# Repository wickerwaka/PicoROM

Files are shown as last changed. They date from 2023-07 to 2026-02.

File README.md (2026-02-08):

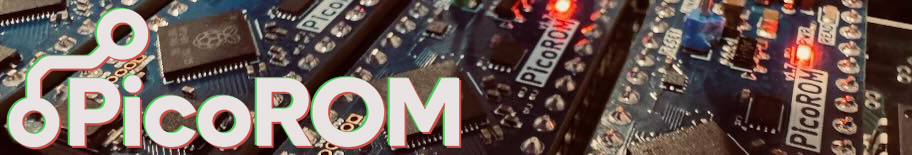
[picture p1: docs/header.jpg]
PicoROM

---
PicoROM is an 8-bit ROM emulator in DIP-32 and DIP-28 form factors. Its primary use case is rapid iteration when experimenting with arcade hardware. PicoROM can emulate ROMs up to 2MBit (256KB) with access times of 70ns. Its compact size allows it to fit into almost any ROM socket regardless of how crowded the board might be.

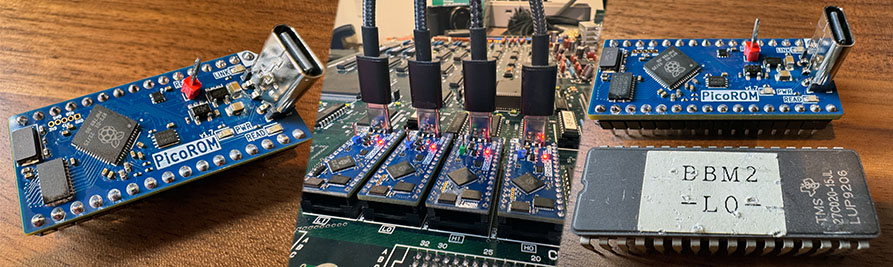
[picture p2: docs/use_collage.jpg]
Header Image


**Features**
- DIP-32 and DIP-28 form factors
- Up to 2MBit (256KB) storage
- 70ns access time
- USB control with integrated firmware updates
- Controllable reset pin

Fully assembled versions are available from [Tindie](https://www.tindie.com/products/pbretro/picorom/).

## Hardware Variants
There are three hardware versions of PicoROM:

- **PicoROM Original (POG)** — Original 32-pin design with a single tri-state reset pin (high, low, or high-impedance). Can be powered by USB or from the host board.
- **PicoROM 28 (P28)** — 28-pin design with dual reset pins (one for high, one for low). Uses split power: the microcontroller is powered by USB or the host board, but external buffers are powered from the 5V input. This reduces power consumption when connected to an unpowered device via USB.
- **PicoROM 32 (P32)** — 32-pin design with all the improvements from P28.

The abbreviated names POG, P28, and P32 identify which firmware image to use for each device.

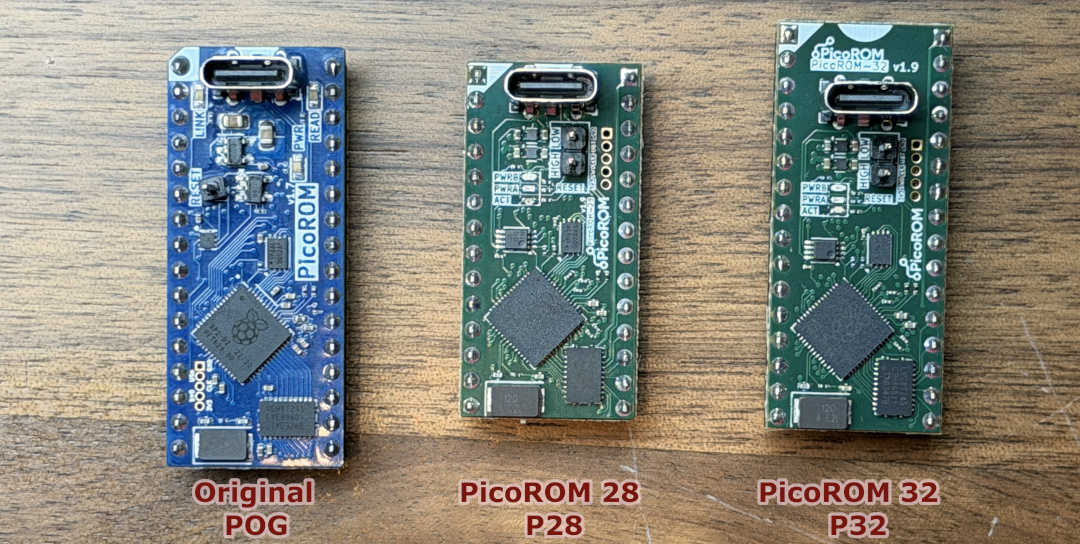
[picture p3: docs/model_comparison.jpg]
Model Comparison


## Version 2.0
Version 2.0 introduced a custom USB protocol, replacing the emulated USB serial port used in version 1.x. The 2.0+ firmware is not compatible with the 1.x `picorom` tool, and vice versa.

## Operation
PicoROM is controlled via USB using the `picorom` command-line tool. The tool can list connected devices, rename them, set parameters, upload ROM data, and update firmware.

Each PicoROM has a name used to identify it in commands. Multiple devices can be connected simultaneously—arcade boards often use multiple ROMs to increase memory size or bus width. List connected devices with `picorom list`:

```console
foo:~ $ picorom list
Available PicoROMs:
  E66138528361BB3  [/dev/cu.usbmodem101]
  E661385490CD014  [/dev/cu.usbmodem102]
```

By default, PicoROMs use a unique hardware ID from flash memory as their name. You can rename devices based on their function—for example, an arcade board with two CPU ROMs (one for the lower 8 bits, one for the upper) could use `cpu_low` and `cpu_high`. These names can then be referenced in makefiles or scripts.

To identify which physical device corresponds to a name, use `picorom identify <name>` to flash its activity LED.

Rename a device with `picorom rename`:

```console
foo:~ $ picorom rename E66138528361BB3 cpu_low
Renamed 'E66138528361BB3' to 'cpu_low'
```

Most commands follow the pattern `picorom <COMMAND> <NAME> <ARGUMENTS...>` where `<NAME>` identifies the target device. The primary command is `upload`, which transfers a binary image to PicoROM:

```console
foo:~ $ picorom upload cpu_low cpu_low.bin
Uploading ROM [################################################################] Done.
```

After upload, PicoROM immediately serves the data for any address requests. Uploaded data is stored in RAM and lost when power is removed. To persist data across power cycles, save it to flash memory using the `-s` flag during upload or the `commit` command afterward:

```console
foo:~ $ picorom upload cpu_low cpu_low.bin -s
Uploading ROM [################################################################] Done.
Storing to Flash - Done.

foo:~ $ picorom commit cpu_low
Storing to Flash - Done.

```

PicoROM defaults to 2MBit mode. If you upload a smaller image, the remaining address space is undefined. To emulate smaller ROM sizes, specify the size during upload:

```console
foo:~ $ picorom upload cpu_low cpu_low_1mbit.bin 1MBit
Uploading ROM [################################################################] Done.
```

You can also download the current ROM contents from a device:

```console
foo:~ $ picorom download cpu_low backup.bin
Downloading ROM [##############################################################] Done.
```

### Reset Control
PicoROM has an external reset pin for controlling the host hardware's reset signal. The pin is a tri-state output: high (+5V), low (ground), or high-impedance (`z`). Use this in build scripts to reset a system after uploading a new ROM:

```make
# picorom makefile target to trigger reset and upload ROM image
picorom: cpu_low.bin cpu_high.bin
    picorom reset cpu_low low
    picorom upload cpu_low cpu_low.bin
    picorom upload cpu_high cpu_high.bin
    picorom reset cpu_low z
```

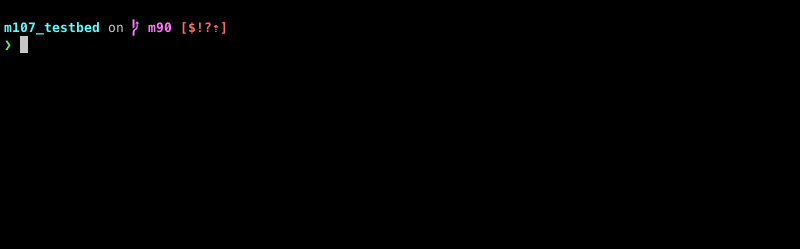
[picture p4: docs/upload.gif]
Upload example


How you interface with each system's reset hardware will vary, and it may not always be possible to override the system's reset signal. The reset pin can also serve as a general-purpose controllable output.

### Standalone Operation
PicoROM draws power from either USB-C or the 5V VCC input at pin 32/28, allowing it to function as a standalone ROM without a USB connection.

At startup, ROM data must be copied from flash to RAM, which takes approximately 8ms. ROM accesses are ignored until this completes. Additional delays may occur while the RP2040 waits for stable supply voltage. Systems with reset circuitry that delays startup for longer than 8ms should work reliably.

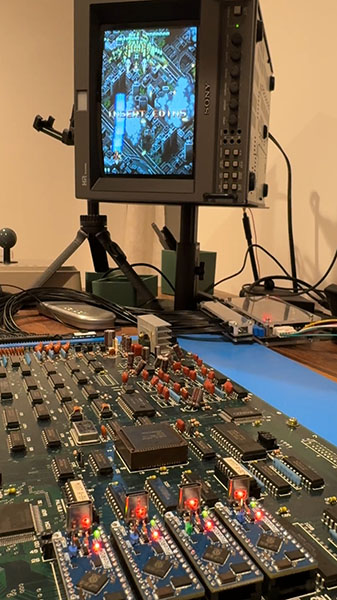
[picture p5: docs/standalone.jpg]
Air Assault M107 running standalone with four PicoROMs
|  |
|:-:|
| *Air Assault M107 running standalone with four PicoROMs* |

The reset pin can mitigate startup timing issues. Set the `initial_reset` parameter to assert a reset value during the initial flash-to-RAM copy:

```console
foo:~ $ picorom set cpu_low initial_reset high
initial_reset=high
```

## Performance
Worst-case access time is 70ns, measured from address assertion to data availability on the data bus. ROM datasheets typically call this "Address to Output Delay." Since PicoROM runs a synchronous instruction loop, access time varies depending on where in the loop the address is asserted.

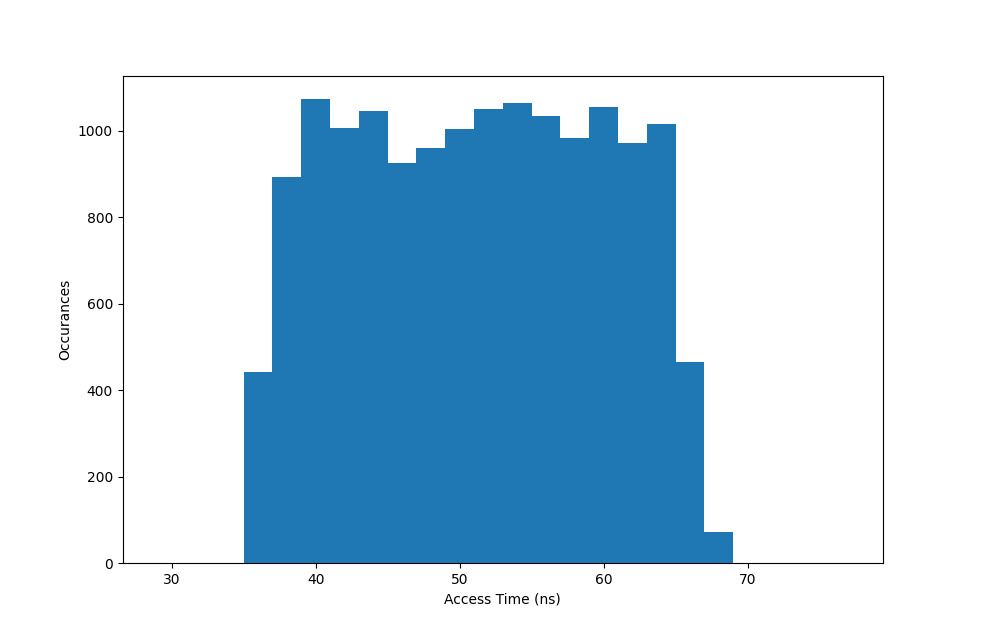
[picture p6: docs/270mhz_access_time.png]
Access time histogram


The delay from output/chip enable assertion to data bus active (Output Enable to Output Delay) is more consistent, with a worst case of 40ns. The inverse delay (enable deasserted to high-impedance) has not been measured but is assumed to be similar.

## Installation
Download the `picorom` command-line application from the [latest release](https://github.com/wickerwaka/PicoROM/releases/latest). Pre-built binaries are available for Windows (Intel), macOS (ARM and Intel), and Linux (ARMv7 and Intel). 
Download the appropriate file for your system from the selection below, place the binary in your PATH and rename it to `picorom` (or `picorom.exe` on Windows).
* Windows: [Intel 64-bit](https://github.com/wickerwaka/PicoROM/releases/latest/download/picorom-x86_64-pc-windows-msvc.exe)
* MacOS: [ARM 64-bit](https://github.com/wickerwaka/PicoROM/releases/latest/download/picorom-aarch64-apple-darwin), [Intel 64-bit](https://github.com/wickerwaka/PicoROM/releases/latest/download/picorom-x86_64-apple-darwin)
* Linux: [Intel 64-bit](https://github.com/wickerwaka/PicoROM/releases/latest/download/picorom-x86_64-unknown-linux-musl), [ARM 32-bit](https://github.com/wickerwaka/PicoROM/releases/latest/download/picorom-armv7-unknown-linux-musleabihf)

The `picorom` tool includes embedded firmware for all hardware variants. To update a device running firmware 2.0 or later:

```console
foo:~ $ picorom firmware cpu_low
```

This will display available firmware versions and flash the selected one. You can also specify a firmware file directly:

```console
foo:~ $ picorom firmware cpu_low path/to/firmware.uf2
```

If a PicoROM becomes unresponsive, force it into USB boot mode by bridging the `USB` and `GND` pads on the header near the RP2040 while powering on.

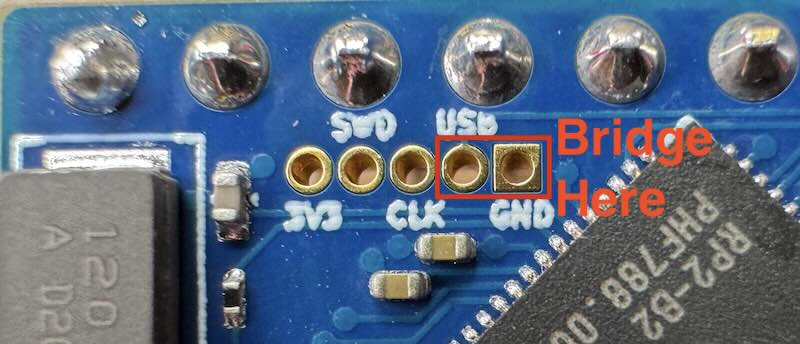
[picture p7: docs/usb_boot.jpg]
USB Boot header location


After flashing, power-cycle the device and verify with `picorom list` and `picorom get <name> version`.

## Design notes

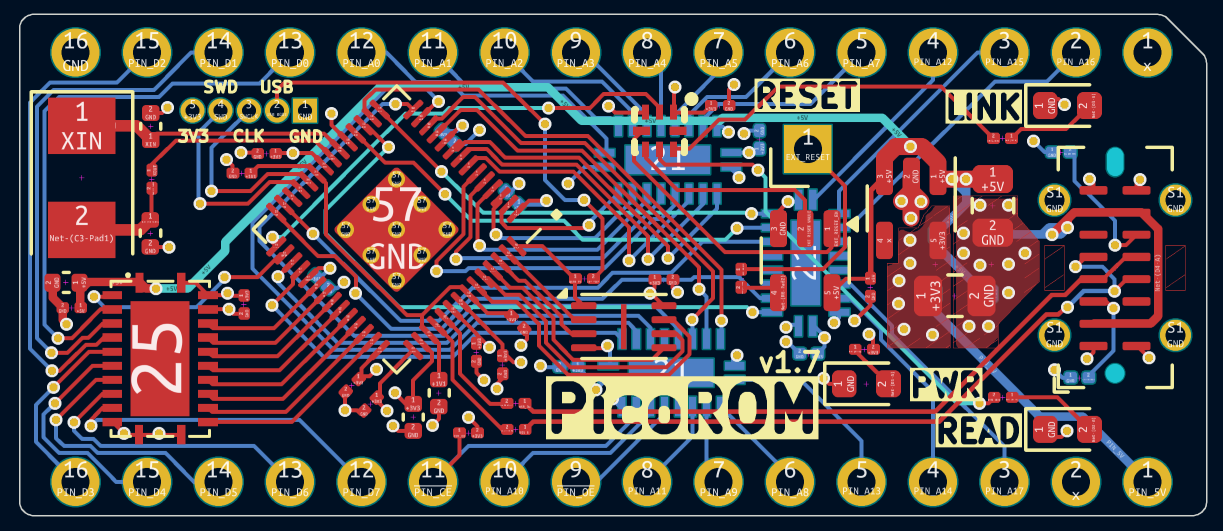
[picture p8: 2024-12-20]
docs/pcb_small.png

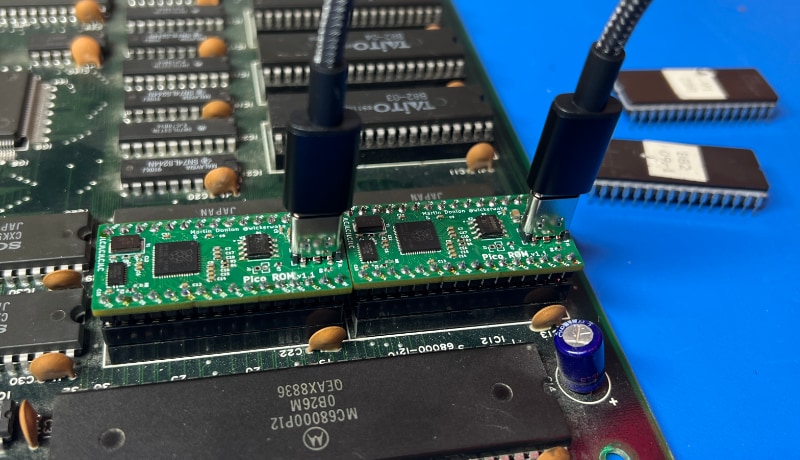
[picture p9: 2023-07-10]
docs/in_use.jpg

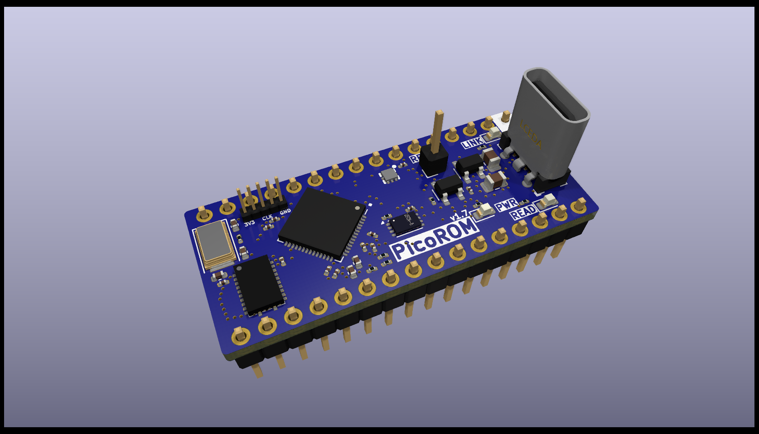
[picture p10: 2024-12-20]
docs/PicoROM_3D.png

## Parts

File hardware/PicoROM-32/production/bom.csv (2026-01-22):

Designator | Footprint | Quantity | Value | LCSC Part #
C1, C10, C25, C26, C27, C4, C8 | 0402 | 7 | 1u | C52923
C11, C12, C13, C14, C15, C16, C17, C18, C19, C20, C21, C22, C23, C24, C5, C6, C7, C9 | 0201 | 18 | 100n | C307380
C2, C3 | 0402 | 2 | 27p | C1557
D1 | 0402 | 1 | Yellow | C434450
D2 | 0402 | 1 | Green | C74338
D3 | 0402 | 1 | Red | C510305
D4, D5 | D_SOD-323 | 2 | NSR0320MW2T1G | C48192
J1 | USB_C_Receptacle_G-Switch_GT-USB-7051x | 1 | USB_C_Receptacle_USB2.0 | C2843970
R1, R10, R11, R14, R2, R29, R5, R8, R9 | 0201 | 9 | 1k | C270335
R3, R4 | 0201 | 2 | 27 | C273268
R6, R7 | 0201 | 2 | 5.1k | C473460
U1, U8 | OnSemi_XDFN4-1EP_1.0x1.0mm_EP0.52x0.52mm | 2 | NCP114AMX330TCG | C133056
U10 | DHVQFN24_L5.5-W3.5-P0.50-BL-EP | 1 | 74LVC8245 | C548858
U2 | Winbond_USON-8-1EP_3x2mm_P0.5mm_EP0.2x1.6mm | 1 | W25Q16JVUXIQ | C2843335
U3 | RP2040-QFN-56 | 1 | RP2040 | C2040
U4, U5, U9 | V-QFN4525-20_L4.5-W2.5-P0.50-BL | 3 | 74LVC245 | C2676234
U6 | VSSOP-8_2.3x2mm_P0.5mm | 1 | 74AHCT2G126 | C554637
U7 | USON-6_L1.5-W1.0-P0.50-BL | 1 | 74LVC1G32 | C7598674
Y1 | Crystal_SMD_5032-2Pin_5.0x3.2mm | 1 | ABM3-12.000MHZ-D2Y-T | C148313

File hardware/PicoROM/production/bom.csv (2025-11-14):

Designator | Footprint | Quantity | Value | LCSC Part #
C1, C4 | 0805 | 2 | 1u | C28323
C10, C25, C8 | 0402 | 3 | 1u | C52923
C11, C12, C13, C14, C15, C16, C17, C18, C19, C20, C21, C22, C23, C24, C5, C6, C7, C9 | 0201 | 18 | 100n | C1525
C2, C3 | 0402 | 2 | 27p | C1557
D1 | 0603 | 1 | LED | C510027
D2 | 0603 | 1 | LED | C2922668
D3 | 0603 | 1 | LED | C2925173
D4, D5 | D_SOD-323 | 2 | NSR0320MW2T1G | C48192
J1 | USB_C_Receptacle_G-Switch_GT-USB-7051x | 1 | USB_C_Receptacle_USB2.0 | C2843970
J5 | PinHeader_1x05_P1.00mm_Vertical | 1 | Conn_01x05_Pin
R1, R10, R2, R5, R8, R9 | 0201 | 6 | 1k | C270335
R11 | 0201 | 1 | 100k | C270364
R3, R4 | 0201 | 2 | 27 | C273268
R6, R7 | 0201 | 2 | 5.1k | C473460
U1 | SOT-23-5 | 1 | AP2112K-3.3 | C51118
U10 | DHVQFN24_L5.5-W3.5-P0.50-BL-EP | 1 | 74LVCH8T245 | C458263
U2 | Winbond_USON-8-1EP_3x2mm_P0.5mm_EP0.2x1.6mm | 1 | W25Q16JVUXIQ | C2843335
U3 | RP2040-QFN-56 | 1 | RP2040 | C2040
U4, U5, U9 | V-QFN4525-20_L4.5-W2.5-P0.50-BL | 3 | 74LVCH245 | C548916
U7 | X2QFN-8_L1.5-W1.5-P0.50-BL | 1 | TCA5405RUGR | C2674123
U8 | SOT-23-5 | 1 | 74AHCT1G126 | C163712
Y1 | Crystal_SMD_5032-2Pin_5.0x3.2mm | 1 | 445C25D12M00000 | C148313

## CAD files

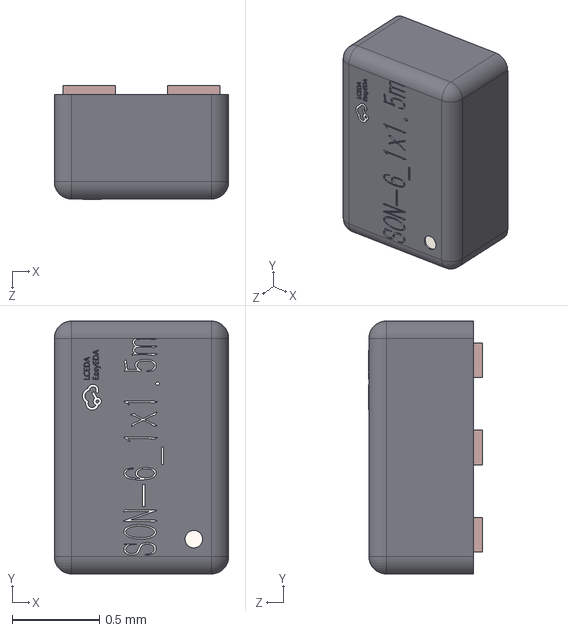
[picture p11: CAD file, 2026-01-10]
hardware/3dshapes/USON-6_L1.5-W1.0-H0.7-P0.50-BL.step
1.00 x 1.45 x 0.651 mm

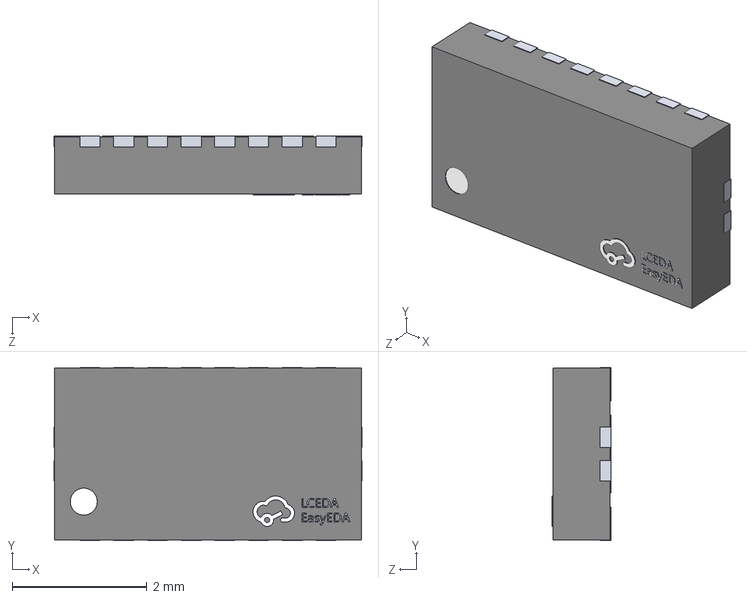
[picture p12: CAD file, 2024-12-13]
hardware/3dshapes/V-QFN4525-20_L4.5-W2.5-P0.50-BL.step
4.57 x 2.57 x 0.87 mm

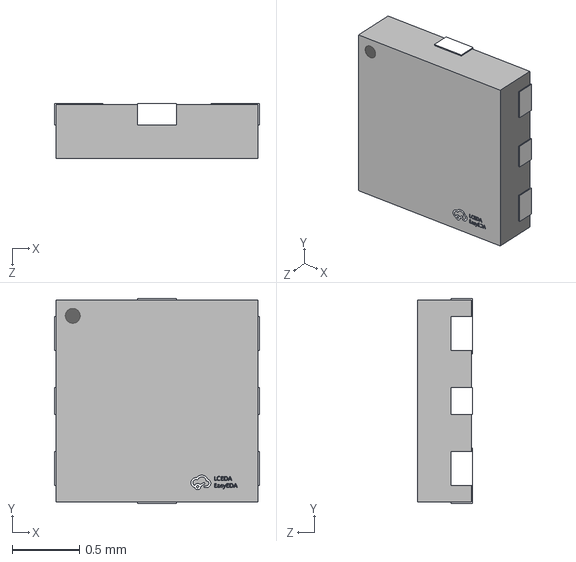
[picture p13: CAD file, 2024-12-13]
hardware/3dshapes/X2QFN-8_L1.5-W1.5-P0.50-BL.step
1.52 x 1.52 x 0.411 mm

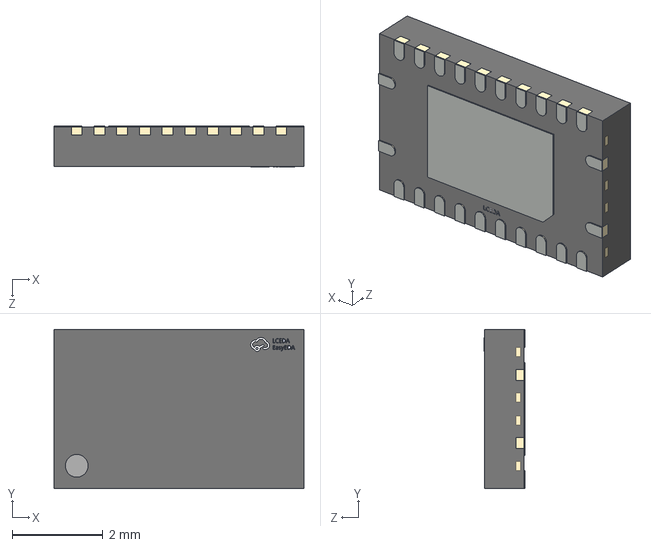
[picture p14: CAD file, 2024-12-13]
hardware/3dshapes/DHVQFN24_L5.5-W3.5-H0.9-P0.50-BL-EP.step
5.50 x 3.50 x 0.91 mm

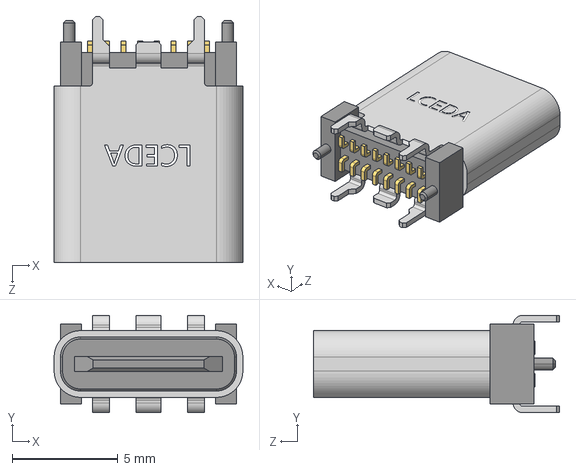
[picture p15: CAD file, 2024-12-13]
hardware/3dshapes/USB-C-SMD_GT-USB-7051A.step
8.94 x 4.60 x 11.7 mm

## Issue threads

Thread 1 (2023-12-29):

How are the boards made?

drudru, 2023-12-29:
Hi, are you getting the boards assembled or are you doing the SMT soldering when you receive the boards?

wickerwaka, 2023-12-29:
No way could I solder these myself without a new set of eyes and just the right amount of alcohol in my system!

I use JLCPCB to do the assembly. BOM, CPL and Gerber files are here: https://github.com/wickerwaka/PicoROM/tree/main/hardware/jlcpcb/production_files

drudru, 2023-12-29:
Heh - I am in the same boat soldering wise.
Thanks for pointing me in the right direction.

Closed 2023-12-29.

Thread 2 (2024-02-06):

3v3-5v support for the address bus?

giulioz, 2024-02-06:
I'm seeing that in the schematics the address bus is connected directly to the PI Pico without any level shifting. Does this means that it's only compatible with 3v3 ROM interfaces and not 5v?

wickerwaka, 2024-02-06:
I have used it exclusively with 5v systems. The RP2040 is not specced as being 5v tolerant, but it seems to handle it pretty well. I wouldn't sell it in this form but I have used it like this for hundreds of hours now without problems. Fitting two more level shifters on there would be pretty difficult and would probably require putting components on the other side of the board.

I use a buffer and level shifter on the data pins because I wanted to ensure it was driving the data lines at a high enough voltage and I also wanted to protect the data pins from 5v input while they were configured as an output, which apparently can be an issue. It also simplified the Output Enable and Chip Select logic in the firmware.

https://hackaday.com/2023/04/05/rp2040-and-5v-logic-best-friends-this-fx9000p-confirms/

giulioz, 2024-02-06:
Neat! Thank you :D

ramapcsx2, 2024-02-07:
Just wanted to add, I read somewhere that one of the designers said that the IOs are practically 5V tolerant, but they couldn't officially claim that for some minor detail .. or so :)

Closed 2024-02-06.

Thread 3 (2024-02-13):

emulate a 16 k Bit EPROM with a standard Raspberry Pi Pico

OE4DEA, 2024-02-13:
I have the use case to emulate a 16 k Bit EPROM with a standard Raspberry Pi Pico. Would this be possible by modifying the GPIOs in the system.h file or would major adjustments have to be made?

wickerwaka, 2024-02-14:
It could be made to work, but a 16KBit EPROM would have a much smaller footprint since it doesn't need as many address pins. Fitting everything into that smaller footprint would be very difficult.

OE4DEA, 2024-02-14:
Since I want to use the standard Raspberry Pi Pico, I don’t see any mechanical problems.My question is more about what adjustments need to be made to the software.Am 14.02.2024 um 05:24 schrieb Martin Donlon ***@***.***>:
It could be made to work, but a 16KBit EPROM would have a much smaller footprint since it doesn't need as many address pins. Fitting everything into that smaller footprint would be very difficult.

—Reply to this email directly, view it on GitHub, or unsubscribe.You are receiving this because you authored the thread.Message ID: ***@***.***>

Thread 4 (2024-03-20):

Does it work with the rp2040 16Mb?

tspfreitas, 2024-03-20:
There is the possibility of using the RP2040 16Mbit, to have a 2MByte rom being compatible with M27c160, the GPIO pinout would have to be revised, but would it be possible? even with some modification to the stock rp2040 changing its spi flash to a 16Mb flash? I found this code very interesting, and I believe it can open doors for many projects, thank you very much for sharing my congratulations

wickerwaka, 2024-03-20:
A 16MBit ROM would not be possible. The flash memory is only used for storing the firmware, configuration data and a copy of the ROM data. The ROM data itself needs to be in RAM, which is only 256Kbytes (2MBit) so that is the maximum size. Even if there was enough RAM space or flash ROM was fast enough, the next limitation would be pin count. All of the GPIO pins are being used. Every doubling in ROM size would require an additional GPIO pin.

JonPrevost, 2024-05-21:
Just a thought; a high speed 3-to-8 or 4-to-16 decoder could save pins. Still limited by the internal RAM size. External SRAM would multiply the project cost.

ramapcsx2, 2024-05-22:
Also, external SRAM tends to access much slower. It really ought to be internal SRAM, and hence everyone waits for the next Pico chip.. hopefully! :)

Closed 2024-03-20.

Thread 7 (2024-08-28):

What would be the equivalent pinout if this software is used on a regular Pi Pico?

hachirokumiku, 2024-08-28:
What is the Pinout for ADDRESS and DATA as laid out on a standard Pi Pico? I.e Does DATA 0-7 correspond to GPIO0,1,2,3,4,5,6,7 etc?

wickerwaka, 2024-08-28:
Happy to answer, but I don't understand the question.

hachirokumiku, 2024-08-28:
Ah, I see it uses an I/O Expander, thanks anyway.

hachirokumiku, 2024-08-29:
> Happy to answer, but I don't understand the question.

I expanded and rephrased my question, in short, i see you built a custom board, but could this be used with a regular pi pico?

wickerwaka, 2024-08-30:
The address pins are GPIO 0-17 and the data pins are GPIO are 22-29. The Pico Pi is 40 pins while this is intended to be used in place of 32-pin ROMS and the layout of the pins with the pico pi would not be compatible with any standard ROM pin layouts because of how the GND and power pins are placed.

dshadoff, 2024-09-28:
...Not to mention that there are several GPIOs which aren't exposed on the Pico board (GPIO 23, 24, 25, 29), so even if one created a "converter" board, and even if that converter board didn't have problems with physical dimensions, it still wouldn't be sufficient electrically.

Closed 2024-12-11.

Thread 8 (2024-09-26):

Feature Request: Raspberry Pi Pico 2

hobopanda, 2024-09-26:
Looking at the new Pico 2 and seen that it has 520K SRAM onboard vs 264K on the Pico 1. With that added 256K you could add support for 512x8 chips with the faster 100ns speed. In my readings so far the new pico 2 also runs faster when overclocked. with faster CPU timings might get faster then 100ns.

wickerwaka, 2025-01-27:
It's something I will investigate once the chips are more available. I'm not sure how much difference the CPU improvements will make, there are some latency differences here and there that might enable some new optimizations.

UffeJakobsen, 2025-01-27:
Please be aware of the current issues with the RP2350

Especially errata E9 causes much concern for others - but a guess that the buffers (may) save you...

RP2350 Errata E9
https://hackaday.com/2024/09/04/the-worsening-raspberry-pi-rp2350-e9-erratum-situation/
https://hackaday.com/2024/09/20/raspberry-pi-rp2350-e9-erratum-redefined-as-input-mode-leakage-current/
https://datasheets.raspberrypi.com/rp2350/rp2350-datasheet.pdf#page=1350

Closed 2025-01-27.

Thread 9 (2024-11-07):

VSYS on the schematic ?

UffeJakobsen, 2024-11-07:
Hi,

Interesting project - thanks for sharing.

One question - the schematic does not show any handling of VSYS in respect produce 3V3 (as far a I can see)

Does that mean that USB needs to be connected in order to feed the Pico ?

PS: I'm looking on the generated PDF in the repo (as I have problems with my KiCad installation right now)

wickerwaka, 2024-11-08:
Yes. In the current designs you need to power it separately through USB. I did this for a few reasons:

- My primary use case is development and iteration, so I always have then hooked up to USB
- While you can store ROM images in flash memory it has to be copied to RAM at startup. I don't know how long this process takes and whether it would be too long for the startup times of most devices.
- I didn't know what the current draw of the PicoROM would be and didn't build it with any concern for that so I was worried about placing any additional load on systems

The current draw turns out to be pretty low (30-50mA). I haven't measure how long the flash copy will take but now that the PicoROM can control an external reset line it, startup time may not be as much of an issue. So for a future revision I may add support for power it without a USB connection.

ramapcsx2, 2024-11-08:
Btw, look at main regulator undervolting for power saving, as well as putting either or both CPU cores to true sleep in intervals.
On ESP32 sleeping the cores is an RTOS operation, where a timer wakes it up some micros later. It conserves a good 50% power.

UffeJakobsen, 2024-11-08:
> Btw, look at main regulator undervolting for power saving, as well as putting either or both CPU cores to true sleep in intervals. On ESP32 sleeping the cores is an RTOS operation, where a timer wakes it up some micros later. It conserves a good 50% power.

@ramapcsx2
That sounds like it is way too slow - this product is essentially a ROM/EPROM emulator
Even when targeting 70'iies, 80'ies it needs to respond in speeds around ~100-200(-300) nano seconds

UffeJakobsen, 2024-11-08:
Hi @wickerwaka

> Yes. In the current designs you need to power it separately through USB. I did this for a few reasons:
>

thanks for clarifying (I thought that I was going blind - looking for a connection between VSYS and VBUS :-D )

>
> The current draw turns out to be pretty low (30-50mA). I haven't measure how long the flash copy will take but now that the PicoROM can control an external reset line it, startup time may not be as much of an issue. So for a future revision I may add support for power it without a USB connection.

Well, as an example the mask roms (kernal, basic, char roms) in a C64 use 30-90 mA (avg ~65 mA) - so I think that you are good to go  :-)

But yes - an option to pull down reset while copying from flash to SRAM would be nice to have. Also multiple units should be able to join in on the same reset line...

Thanks :-)

wickerwaka, 2024-12-13:
#13 adds support for powering from vsys

UffeJakobsen, 2024-12-13:
> #13 adds support for powering from vsys

Nice - thanks :+1:

Closed 2024-12-13.

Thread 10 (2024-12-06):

No longer compiling with current sdk

sbrk-r, 2024-12-06:
Hi, great project!

It seems the library function, 'set_sys_clock_khz()' has been moved into "hardware/clocks.h"

After making that change I was able to compile and it seems to work - I don't have real hardware yet, but a dev board enumerates and communicates with the picorom host software.

PS - any reason to not have a fast OR or NOR gate summing CE# and OE# to free up a pin..? I think I'd like to change the IO expander to something a bit more traditional and visible to the naked eye.

wickerwaka, 2024-12-06:
Thanks. I have another branch that I'm doing some cleanup in and already have this fix there, I will merge it back into main soon.

As far as the /CE and /OE pins are concerned. Yeah, it would be nice to use an I2C IO expander instead of the pretty obscure TI one-wire part. Also having the /CE and /OE inputs combined externally would make some of the PIO code a lot simpler because it could just wait or jump based on a single pin value.

The reason I haven't done this is because I want to maintain compatibility with as many ROM pinouts as possible. Someone recently needed to use this to replace a non-JEDEC 27C1000 which has A16 and /OE swapped. I was able to make some changes to the firmware to support that, which I wouldn't have been able to do if that signal was being combined externally. Will probably never be needed again, but I want to maintain as much flexibility as possible.

I've also considered using Dual SPI instead of Quad SPI for the flash since flash access speed isn't critical. That would free up two pins that could be used to bit-bang I2C from the CPU.

sbrk-r, 2024-12-10:
That makes sense. Dropping to dual spi is interesting, I hadn't realized those pins could be repurposed.

sbrk-r, 2025-03-11:
Reopening because I can't figure out how to talk to you otherwise, sorry if that is annoying (!)

My immediate use for this is 28pin EPROMs, probably would have been smarter to just build an adapter but I kludged a board together instead...
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

Very few hardware changes, added an OR gate summing OE# and CE# and putting them in the old OE# pin (20). old CE# pin (21) and TCA IO expander pin (18) are routed to a PCA8574. Bit easier to solder by hand.

Unfortunately I read the datasheet _after_ I submitted it to the board house, and you need sequential pins for the HW I2C (also stipulated in the PIO I2C example). So I'll have to figure out something in software, and learn more about the PIO.

Strangely, though - it works with the stock firmware (ignoring expander functions). Since CE# is now used for I2C and pulled up with a resistor, it should never trigger the !OE && !CE logic, unless i misinterpreted that... maybe there is some bug there. or my board has a short.

sbrk-r, 2025-07-15:
(back from vacation now) Yes! I meant to update. I forgot I had jumpers that defaulted to the same pinout of OE# and CE# as your board, so it could be used with either IO expander. I also inadvertently left the LEDs as grounded cathode with won't work with an open collector driver (PCA8574), but with one wire mod I did get it to work without issues... other than writing the software which took a bit to get my head around RP2040.

It's not too elegant but the changes are in my fork at https://github.com/sbrk-r/pikorom if you were curious.

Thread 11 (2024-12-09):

Too slow for intel Pentium 100 motherboard ?

Deksor, 2024-12-09:
Hello !
This project is going to be really helpful for me to debug an AT 286 motherboard that has some issues and LOTS of components to test (it's mostly made of glue logic).

### Problem
I just built one myself, and during testing, while it seems like it's doing ok in a 386 motherboard, it's struggling to get a Pentium board to POST.

What I did is that I took out the original ROM (which contains an award BIOS v4.51PG), dumped it, then flashed the bin file to the picorom while making sure of using the right size (1MBit).
Then I put a POST card into an ISA slot of the motherboard to monitor the activity and finally I turned it on.

The board executes some code, but after a while hangs.
When I put back the original ROM chip in place of the picorom, the board POSTs fine to the memory count screen, so the motherboard works fine.

Here's a video of the picorom in action https://youtu.be/1Ub2xlTqZPE

### Informations / context
Then I pulled off the sticker of the ROM chip and it's an Atmel AT29C010A-**15PC** AKA 150ns ROM according to the datasheet, yet the picorom is said to be able to run at 100ns.

If you need informations about the motherboard, it's a PcPartner TXB820DS https://theretroweb.com/motherboards/s/pcpartner-txb820ds-35-8333-00,35-8333-01,35
CPU is a Pentium 100

Just for your information if you've never used a POST card, the relevant pair of hex numbers is the one at the top. It starts with C1 on an award BIOS which is normal, then does some progress and finally hangs at 0x05 which is according to here https://blog.theretroweb.com/2024/01/20/award-bios-beep-and-post-codes-list/ after "keyboard initialization". Referring to the "version 4.0" it might be hanging during the next code 0x06 aka "ROM checksum" (though 0x06 is missing from the listing for version 4.51PG I think it's still where it hangs ...)

I also tried the picorom in a TL866 and the file it outputed was exactly identical to the original one, so I think my unit is working just as expected.

I used this version of the firmware https://github.com/wickerwaka/PicoROM/releases/download/v1.5/PicoROM.uf2 on the pico.

### Conclusion
Can you help me ?
I can provide any other piece of information needed for the troubleshoot

wickerwaka, 2024-12-10:
It's possible it's still too slow, I need to go back and run some speed tests on the 1.5 version with a new benchmarking version I have setup.

With the latest version I am overclocking the CPU more and the access time is 70ns. It's not merged into main, try this firmware here: https://github.com/wickerwaka/PicoROM/actions/runs/12249629253/artifacts/2297819714

Deksor, 2024-12-10:
Thanks a lot for the new firmware.

I tried it and now the board posts !

However multiple times it also got stuck at code C0 which is the very first one with that bios afaik.

I didn't have the time to experiment more so, in this case, maybe it's just a hiccup from the motherboard, I'll see tonight if I can try it more.

wickerwaka, 2024-12-10:
At this speed the access time should be more than enough to match the 150ns of the original ROM. I wonder if I'm not hitting some of the other timing expectations.

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

The "/CE or /OE to Output Float" time at 40ns might be right on the border. I made a slight firmware change that should turn off the buffer about 8ns faster. Maybe it'll fix it, but probably not.

https://github.com/wickerwaka/PicoROM/actions/runs/12265755534/artifacts/2302710479

Let me know.

Deksor, 2024-12-10:
This is much better.
It still crashes sometimes early in the POST, but it seems to be related to the power on cycle, not sure exactly why. I couldn't get it to crash later, during POST or anywhere.

wickerwaka, 2024-12-10:
Okay good. I'm going to try to build some tests to measure these other values.

wickerwaka, 2025-01-27:
If you are still experimenting with this, please try the latest firmware (version 1.7).

Deksor, 2025-01-28:
Yes I'm still experimenting !

You did a great job !

No more crash early during POST, however the board seems to have developped a fault with the keyboard, it's really strange. I'm going to investigate more with another motherboard, I'm not sure if the cause is actual hardware or something else.

I've also had an error I've never seen after it POSTed where it displayed "Unknown flash", but I assue this is because the motherboard is trying to flash the PNP table or something like this (I can't remember what this is called exactly but TLDR the board tries to write something to the rom but doesn't recognise its type ; actually maybe adding a fake ROM identifier that would be recognized by most hardware could be added ?). Also I'm not sure if as-is the picorom can be written to by the destination board.
I know you said it can be used to communicate between host and destination board through the picorom in a previous version of readme, but that's an entirely different thing (very nice feature though, that will be handy in my upcoming projects 😄 )

Anyways, let me investigate more on different motherboards, but so far it seems promising !

Closed 2024-12-10.

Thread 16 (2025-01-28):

Linux picorom executable doesn't recognise the picoroms connected to the PC, but my compiled executable does [Debian 12]

Deksor, 2025-01-28:
### Problem

I downloaded the linux version of the picorom tool and tried to execute it. The tool runs, but for some reason it doesn't recognise my pico.
I can see the "link" led flash on my picos when I run that command, but yeah they're not being recognized as the program returns "No PicoROMs found."

Meanwhile I compiled the repo's code and it detects them fine.

### Informations / context

My system is based on ryzen 5000 series with x570 chipset and I run Debian 12. My user is part of the dialout group in order to have access to the pico.

wickerwaka, 2025-01-28:
Can you confirm that you are using the 1.7 version of the firmware and the picorom tool?

Deksor, 2025-01-28:
Yes ! I downloaded the new host program right after I flashed my pico

wickerwaka, 2025-01-28:
Thanks. I'll see if I can reproduce it tonight.

wickerwaka, 2025-01-29:
Fixed by 21f895213d67d2e4af0787dfe27bbebee17e2007

Closed 2025-01-29.

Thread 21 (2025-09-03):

Right Angle / Horizontal USB-C Connector?

sbelectronics, 2025-09-03:
Hi, I was wondering if there are any known right-angle/horizontal USB-C connectors that are compatible with the footprint for the vertical connector on the PicoROM module? When I design my pcboards, it's often with the ROM(s) near the edge of the board, with the top pointed off-board (where I usually fit a ZIF) socket, and it would be convenient to have a variant where the connector executed parallel to the pcboard rather than perpendicular to it.

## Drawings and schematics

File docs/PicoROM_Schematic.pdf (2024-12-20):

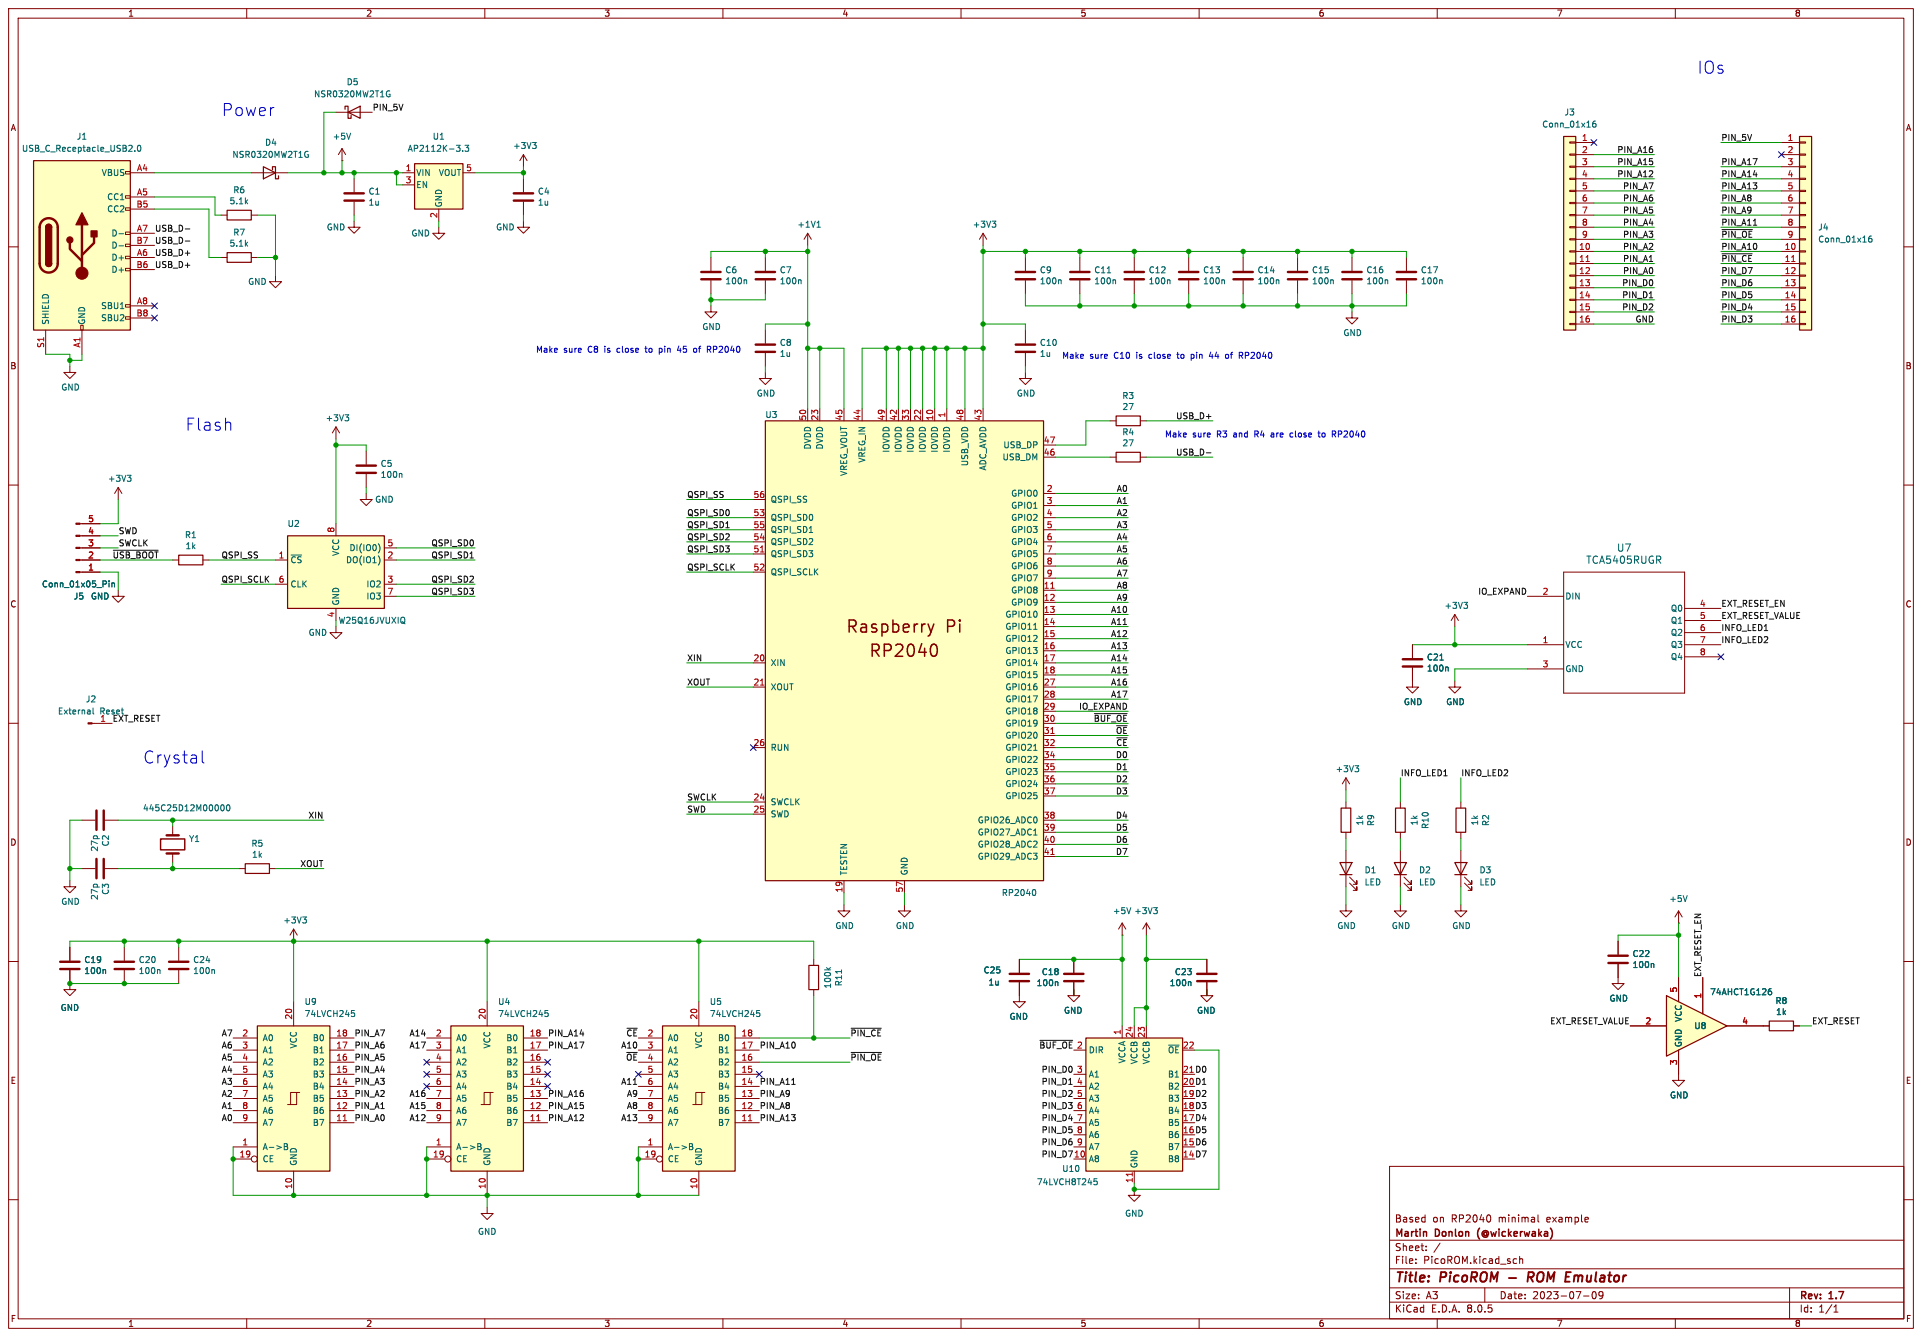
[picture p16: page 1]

1 IOVDD 10 GPIO8 11 GPIO9 12 GPIO10 13 GPIO11 14 GPIO12 15 GPIO13 16 GPIO14 17 GPIO15 18 TESTEN 19 GPIO0 2 XIN 20 XOUT 21 IOVDD 22 DVDD 23 SWCLK 24 SWD 25 RUN 26 GPIO16 27 GPIO17 28 GPIO18 29 GPIO1 3 GPIO19 30 GPIO20 31 GPIO21 32 IOVDD 33 GPIO22 34 GPIO23 35 GPIO24 36 GPIO25 37 GPIO26_ADC0 38 GPIO27_ADC1 39 GPIO2 4 GPIO28_ADC2 40 GPIO29_ADC3 41 IOVDD 42 ADC_AVDD 43 VREG_IN 44 VREG_VOUT 45 USB_DM 46 USB_DP 47 USB_VDD 48 IOVDD 49 GPIO3 5 DVDD 50 QSPI_SD3 51 QSPI_SCLK 52 QSPI_SD0 53 QSPI_SD2 54 QSPI_SD1 55 QSPI_SS 56 GND 57 GPIO4 6 GPIO5 7 GPIO6 8 GPIO7 9 U3 RP2040 1kR9 +3V3 +3V3 GND

1 A8 10 GND 11 B8 14 B7 15 B6 16 B5 17 B4 18 B3 19 DIR 2 B2 20 B1 21 ~{OE} 22 VCCB 23 VCCB 24 A1 3 A2 4 A3 5 A4 6 A5 7 A6 8 A7 9 U10
PIN_D1 PIN_D0 PIN_D3 ~{BUF_OE} PIN_D2

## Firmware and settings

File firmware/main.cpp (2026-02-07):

#include "hardware/gpio.h"
#include "hardware/structs/syscfg.h"
#include "pico/bootrom.h"
#include "pico/time.h"
#include <stdio.h>
#include <unistd.h>

#include <tusb.h>

#include "comms.h"
#include "flash.h"
#include "peripherals.h"
#include "pico_link.h"
#include "pio_programs.h"
#include "rom.h"
#include "str_util.h"
#include "system.h"

#include "build_time.h"

// Dummy atexit implementation because some SDK/newlib versions don't strip
// atexit and it uses several 100bytes of RAM
int __wrap_atexit(void *)
{
    return 0;
}

void configure_address_pins(uint32_t mask)
{
    mask &= ADDR_MASK;

    // configure address lines
    for (uint ofs = 0; ofs < N_ADDR_PINS; ofs++)
    {
        uint gpio = BASE_ADDR_PIN + ofs;

        gpio_init(gpio);
        gpio_set_pulls(gpio, false, true);
        gpio_set_input_hysteresis_enabled(gpio, false);
        syscfg_hw->proc_in_sync_bypass |= 1 << gpio;

        if (mask & (1 << ofs))
        {
            gpio_set_input_enabled(gpio, true);
        }
        else
        {
            gpio_set_input_enabled(gpio, false);
        }
    }
}

uint32_t flash_load_time = 0;
uint32_t system_status = 0;

// Flag to trigger USB re-enumeration from main loop (not safe in USB callback)
static bool usb_reenumerate_pending = false;

static Config config;

static const char *parameter_names[] = {"name",          "rom_name",   "addr_mask", "rom_size",     "initial_reset",
                                        "default_reset", "reset",      "status",    "startup_time", "build_config",
                                        "build_version", "build_time", nullptr};

bool set_parameter(const char *name, const char *value)
{
    if (streq(name, "addr_mask"))
    {
        config.addr_mask = strtoul(value) & ADDR_MASK;
        configure_address_pins(config.addr_mask);
        return true;
    }
    else if (streq(name, "name"))
    {
        strcpyz(config.name, sizeof(config.name), value);
        flash_save_config(&config);
        usb_reenumerate_pending = true;
        return true;
    }
    else if (streq(name, "rom_name"))
    {
        strcpyz(config.rom_name, sizeof(config.name), value);
        return true;
    }
    else if (streq(name, "initial_reset"))
    {
        if (reset_from_string(value, &config.initial_reset))
        {
            flash_save_config(&config);
            return true;
        }
    }
    else if (streq(name, "default_reset"))
    {
        if (reset_from_string(value, &config.default_reset))
        {
            flash_save_config(&config);
            return true;
        }
    }
    else if (streq(name, "reset"))
    {
        ResetLevel level;
        if (reset_from_string(value, &level))
        {
            reset_set(level);
            return true;
        }
        else
        {
            return false;
        }
    }
    return false;
}

bool get_parameter(const char *name, char *value, size_t value_size)
{
    if (streq(name, "addr_mask"))
    {
        snprintf(value, value_size, "0x%08x", config.addr_mask);
        return true;
    }
    else if (streq(name, "rom_size"))
    {
        snprintf(value, value_size, "0x%08x", ROM_SIZE);
        return true;
    }
    else if (streq(name, "name"))
    {
        strcpyz(value, value_size, config.name);
        return true;
    }
    else if (streq(name, "rom_name"))
    {
        strcpyz(value, value_size, config.rom_name);
        return true;
    }
    else if (streq(name, "status"))
    {
        snprintf(value, value_size, "0x%08x", system_status);
        return true;
    }
    else if (streq(name, "startup_time"))
    {
        snprintf(value, value_size, "%d", flash_load_time);
        return true;
    }
    else if (streq(name, "initial_reset"))
    {
        reset_to_string(config.initial_reset, value, value_size);
        return true;
    }
    else if (streq(name, "default_reset"))
    {
        reset_to_string(config.default_reset, value, value_size);
        return true;
    }
    else if (streq(name, "reset"))
    {
        reset_to_string(reset_get(), value, value_size);
        return true;
    }
    else if (streq(name, "build_config"))
    {
        strcpyz(value, value_size, PICOROM_CONFIG_NAME);
        return true;
    }
    else if (streq(name, "build_version"))
    {
        strcpyz(value, value_size, PICOROM_FIRMWARE_VERSION);
        return true;
    }
    else if (streq(name, "build_time"))
    {
        strcpyz(value, value_size, PICOROM_BUILD_TIME);
        return true;
    }

    return false;
}

// Packet handler - called from USB RX callback
void handle_packet(const Packet *req)
{
    switch ((PacketType)req->type)
    {
    case PacketType::Write:
    {
        if (req->size < 4)
        {
            pl_send_error("Write too small", 0, req->size);
            break;
        }
        uint32_t offset;
        memcpy(&offset, req->payload, sizeof(uint32_t));
        uint32_t data_size = req->size - 4;
        if ((offset + data_size) > ROM_SIZE)
        {
            pl_send_error("Write out of range", offset, data_size);
            break;
        }
        memcpy(rom_get_buffer() + offset, req->payload + 4, data_size);
        break;
    }

    case PacketType::Read:
    {
        if (req->size < 5)
        {
            pl_send_error("Read too small", 0, req->size);
            break;
        }
        uint32_t offset;
        memcpy(&offset, req->payload, sizeof(uint32_t));
        uint32_t requested = req->payload[4];
        uint32_t available = (offset < ROM_SIZE) ? (ROM_SIZE - offset) : 0;
        uint32_t max_data = MAX_PKT_PAYLOAD - 4;
        uint32_t size = MIN(MIN(requested, max_data), available);
        pl_send_payload_offset(PacketType::ReadData, offset, rom_get_buffer() + offset, size);
        break;
    }

    case PacketType::CommitFlash:
    {
        flash_save_rom();
        flash_save_config(&config);
        pl_send_null(PacketType::CommitDone);
        break;
    }

    case PacketType::CommsStart:
    {
        uint32_t addr;
        memcpy(&addr, req->payload, 4);
        comms_begin_session(addr, rom_get_buffer());
        pl_send_debug("Comms Started", addr, 0);
        break;
    }

    case PacketType::CommsEnd:
    {
        comms_end_session();
        pl_send_debug("Comms Ended", 0, 0);
        break;
    }

    case PacketType::CommsData:
    {
        if (!comms_update(req->payload, req->size, 5000))
        {
            pl_send_error("Comms send timeout", 0, 0);
        }
        break;
    }

    case PacketType::SetParameter:
    {
        char *split = (char *)memchr(req->payload, ',', req->size);
        if (split != nullptr)
        {
            *split = '\0';
            if (set_parameter((char *)req->payload, split + 1))
            {
                Packet pkt;
                if (get_parameter((const char *)req->payload, (char *)pkt.payload, sizeof(pkt.payload)))
                {
                    pkt.size = strlen((char *)pkt.payload);
                    pkt.type = (uint8_t)PacketType::Parameter;
                    pl_send_packet(&pkt);
                }
                else
                {
                    pl_send_null(PacketType::ParameterError);
                }
                break;
            }
            else
            {
                pl_send_null(PacketType::ParameterError);
            }
        }
        else
        {
            pl_send_null(PacketType::ParameterError);
        }
        break;
    }

    case PacketType::GetParameter:
    {
        Packet pkt;
        if (get_parameter((const char *)req->payload, (char *)pkt.payload, sizeof(pkt.payload)))
        {
            pkt.size = strlen((char *)pkt.payload);
            pkt.type = (uint8_t)PacketType::Parameter;
        }
        else
        {
            pkt.size = 0;
            pkt.type = (uint8_t)PacketType::ParameterError;
        }
        pl_send_packet(&pkt);
        break;
    }

    case PacketType::QueryParameter:
    {
        if (req->size == 0)
        {
            pl_send_string(PacketType::Parameter, parameter_names[0]);
        }
        else
        {
            const char **p = parameter_names;
            while (p)
            {
                if (!strcmp(*p, (char *)req->payload))
                {
                    p++;
                    break;
                }
                p++;
            }

            if (p)
                pl_send_string(PacketType::Parameter, *p);
            else
                pl_send_null(PacketType::Parameter);
        }
        break;
    }

    case PacketType::Identify:
    {
        trigger_identify_led();
        break;
    }

    default:
    {
        pl_send_error("Unrecognized packet", req->type, req->size);
        break;
    }
    }
}

int main()
{
    flash_init_config(&config);

    if (pio_programs_init())
    {
        system_status |= STATUS_PIO_INIT;
    }

    // We have to initialize these pins before starting the rom programs
    peripherals_init();

    rom_init_programs();

    reset_set(config.initial_reset);

    flash_load_time = flash_load_rom();

    tusb_init();

    pl_init(handle_packet);

    configure_address_pins(config.addr_mask);

    rom_service_start();

    reset_set(config.default_reset);

    // Arm initial RX transfer
    tud_vendor_read_flush();

    while (true)
    {
        tud_task();

        if (usb_reenumerate_pending)
        {
            usb_reenumerate_pending = false;
            // Allow USB response to complete before disconnecting
            sleep_ms(50);
            tud_task();
            tud_disconnect();
            sleep_ms(250);
            tud_connect();
        }

        comms_update(nullptr, 0, 5000);
    }
}

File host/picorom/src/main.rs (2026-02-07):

use anyhow::Result;
use clap::{Parser, Subcommand};
use std::path::PathBuf;

mod commands;
mod embedded_firmware;
mod firmware;
mod rom_size;
mod uf2;

use crate::rom_size::RomSize;

#[derive(Debug, Parser)]
#[command(name = "picorom")]
#[command(about = "PicoROM controller", long_about = None)]
struct Cli {
    #[command(subcommand)]
    command: Commands,
}

#[derive(Debug, Subcommand)]
enum Commands {
    /// Return a list of currently connected PicoROM devices.
    List,

    /// Flash the activity LED on a specific PicoRom
    Identify {
        /// PicoROM device name.
        name: String,
    },

    /// Commit the current ROM image to flash memory
    Commit {
        /// PicoROM device name.
        name: String,
    },

    /// Change the name of a PicoROM device.
    Rename {
        /// Current name.
        current: String,
        /// New name to rename it to.
        new: String,
    },

    /// Swap the names of two PicoROM devices.
    NameSwap {
        /// First device name.
        first: String,
        /// Second device name.
        second: String,
    },

    /// Upload a ROM image to a PicoROM
    Upload {
        /// PicoROM device name.
        name: String,
        /// Path of file to upload.
        source: PathBuf,
        /// Emulate a specific ROM size. If not specified, uses the device's current rom_size.
        #[arg(value_enum, ignore_case = true)]
        size: Option<RomSize>,
        /// Store the uploaded image in flash memory also.
        #[arg(short, long, default_value_t = false)]
        store: bool,
    },

    /// Download the current ROM image from a PicoROM to a file
    Download {
        /// PicoROM device name.
        name: String,
        /// Destination file path.
        dest: PathBuf,
    },

    /// Set the level of the reset pin
    Reset {
        /// PicoROM device name.
        name: String,

        /// Reset level
        #[arg(value_parser = clap::builder::PossibleValuesParser::new(["high", "low", "z"]))]
        level: String,
    },

    /// Get the value of a parameter
    Get {
        /// PicoROM device name.
        name: String,

        /// Parameter name
        param: Option<String>,
    },

    /// Set a parameter to a new value
    Set {
        /// PicoROM device name.
        name: String,

        /// Parameter name
        param: String,

        /// Parameter value
        value: String,
    },

    /// Upload firmware to a PicoROM device
    Firmware {
        /// PicoROM device name (optional if only one device connected)
        name: Option<String>,
        /// Path to firmware file (.uf2 or .bin) - if omitted, select from embedded firmware
        #[arg(short = 'f', long = "file")]
        firmware: Option<PathBuf>,
        /// Skip confirmation prompt
        #[arg(short = 'y', long)]
        yes: bool,
        /// Don't reboot after flashing
        #[arg(long)]
        no_reboot: bool,
    },
}

fn main() -> Result<()> {
    let args = Cli::parse();

    match args.command {
        Commands::List => commands::list::run()?,
        Commands::Identify { name } => commands::identify::run(&name)?,
        Commands::Commit { name } => commands::commit::run(&name)?,
        Commands::Rename { current, new } => commands::rename::run(&current, &new)?,
        Commands::NameSwap { first, second } => commands::rename::run_swap(&first, &second)?,
        Commands::Upload {
            name,
            source,
            size,
            store,
        } => commands::upload::run(&name, &source, size, store)?,
        Commands::Download { name, dest } => commands::download::run(&name, &dest)?,
        Commands::Reset { name, level } => commands::reset::run(&name, &level)?,
        Commands::Get { name, param } => commands::parameter::run_get(&name, param.as_deref())?,
        Commands::Set { name, param, value } => {
            commands::parameter::run_set(&name, &param, &value)?
        }
        Commands::Firmware {
            name,
            firmware,
            yes,
            no_reboot,
        } => commands::firmware::run(name.as_deref(), firmware.as_deref(), yes, no_reboot)?,
    }

    Ok(())
}

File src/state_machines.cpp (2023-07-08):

#include "state_machines.h"
#include "system.h"

#include "data_bus.pio.h"

static PIO data_pio = pio0;
static PIO addr_pio = pio1;

void init_data_bus_programs()
{
    uint sm_data = pio_claim_unused_sm(data_pio, true);
    uint sm_oe = pio_claim_unused_sm(data_pio, true);

    // Assign data and oe pins to pio
    for( uint ofs = 0; ofs < N_DATA_PINS; ofs++ )
    {
        pio_gpio_init(data_pio, BASE_DATA_PIN + ofs);
        gpio_set_input_enabled(BASE_DATA_PIN + ofs, false);
    }

    for( uint ofs = 0; ofs < N_OE_PINS; ofs++ )
    {
        pio_gpio_init(data_pio, BASE_OE_PIN + ofs);
    }

    for( uint ofs = 0; ofs < N_BUF_OE_PINS; ofs++ )
    {
        pio_gpio_init(data_pio, BASE_BUF_OE_PIN + ofs);
        gpio_set_input_enabled(BASE_BUF_OE_PIN + ofs, false);
    }

    // OUTPUT_BUFFER==0 does this in the oe program
#if OUTPUT_BUFFER==1
    pio_sm_set_consecutive_pindirs(data_pio, sm_data, BASE_DATA_PIN, N_DATA_PINS, true);
#endif

    // set out/in bases
    uint offset_data = pio_add_program(data_pio, &output_program);
    pio_sm_config c_data = output_program_get_default_config(offset_data);

    sm_config_set_out_pins(&c_data, BASE_DATA_PIN, N_DATA_PINS);
    sm_config_set_out_shift(&c_data, true, true, N_DATA_PINS);
    pio_sm_init(data_pio, sm_data, offset_data, &c_data);
    pio_sm_set_enabled(data_pio, sm_data, true);

    // set oe pin directions, data pin direction will be set by the sm
    pio_sm_set_consecutive_pindirs(data_pio, sm_oe, BASE_OE_PIN, N_OE_PINS, false);
    pio_sm_set_consecutive_pindirs(data_pio, sm_oe, BASE_BUF_OE_PIN, N_BUF_OE_PINS, true);

#if OUTPUT_BUFFER==1
    uint offset_oe = pio_add_program(data_pio, &output_enable_buffer_program);
    pio_sm_config c_oe = output_enable_buffer_program_get_default_config(offset_oe);
    sm_config_set_in_pins(&c_oe, BASE_OE_PIN);
    sm_config_set_set_pins(&c_oe, BASE_BUF_OE_PIN, N_BUF_OE_PINS);
#else
    uint offset_oe = pio_add_program(data_pio, &output_enable_program);
    pio_sm_config c_oe = output_enable_program_get_default_config(offset_oe);
    sm_config_set_in_pins(&c_oe, BASE_OE_PIN);
    sm_config_set_out_pins(&c_oe, BASE_DATA_PIN, N_DATA_PINS);
#endif
    pio_sm_init(data_pio, sm_oe, offset_oe, &c_oe);
    pio_sm_set_enabled(data_pio, sm_oe, true);
}

io_wo_32 *get_data_bus_fifo()
{
    return &data_pio->txf[0];
}


void start_comms_programs(uint32_t addr, uint32_t byte_offset)
{
    pio_clear_instruction_memory(addr_pio);

    uint32_t offset_write = pio_add_program(addr_pio, &detect_write_program);
    uint32_t offset_read = pio_add_program(addr_pio, &detect_read_program);

    pio_sm_config c_write = detect_write_program_get_default_config(offset_write);
    sm_config_set_in_pins(&c_write, 0);
    pio_sm_init(addr_pio, 0, offset_write, &c_write);
    pio_sm_set_enabled(addr_pio, 0, true);
    pio_sm_put_blocking(addr_pio, 0, (addr + 0x100) >> 8);
    pio_set_irq0_source_enabled(addr_pio, pis_sm0_rx_fifo_not_empty, true);

    pio_sm_config c_read = detect_read_program_get_default_config(offset_read);
    sm_config_set_in_pins(&c_read, 0);
    pio_sm_init(addr_pio, 1, offset_read, &c_read);
    pio_sm_set_enabled(addr_pio, 1, true);
    pio_sm_put_blocking(addr_pio, 1, addr + byte_offset);
    pio_set_irq1_source_enabled(addr_pio, pis_sm1_rx_fifo_not_empty, true);
}

void end_comms_programs()
{
    pio_sm_set_enabled(addr_pio, 0, false);
    pio_sm_set_enabled(addr_pio, 1, false);
}

bool comms_poll_write(uint8_t *out)
{
    if (pio_sm_get_rx_fifo_level(addr_pio, 0) > 0)
    {
        *out = pio_sm_get(addr_pio, 0);
        return true;
    }

    return false;
}


bool comms_poll_read()
{
    bool was_read = false;
    while( pio_sm_get_rx_fifo_level(addr_pio, 1) > 0 )
    {
        pio_sm_get(addr_pio, 1);
        was_read = true;
    }

    return was_read;
}

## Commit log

2023-06-18 Initial commit with docs and hacked up schematic
    [RP2040_minimal-BOM.xlsx, RP2040_minimal.kicad_pcb, RP2040_minimal.kicad_sch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]
2023-06-19 Completed routing
    [RP2040_minimal.kicad_pcb, RP2040_minimal.kicad_sch]
2023-06-21 Switch to 3/5mm vias
    [RP2040_minimal.kicad_pcb, RP2040_minimal.kicad_sch]
2023-06-22 v1.0 submitted for manufacture
    [RP2040_minimal.kicad_pcb, RP2040_minimal.kicad_sch]
2023-06-22 Rename kicad project
    [PicoROM-CuBottom.gbr, PicoROM-CuIn1.gbr, PicoROM-CuIn2.gbr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]
2023-06-27 Added debug header
    [PicoROM.kicad_pcb, PicoROM.kicad_sch]
2023-06-30 Added buffer to data bus
    [PicoROM-CuBottom.gbr, PicoROM-CuIn1.gbr, PicoROM-CuIn2.gbr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]
2023-07-07 Use interrupts for two way comms WIP support for output buffer
2023-07-08 Final fixes for buffered output
    [state_machines.cpp]
2023-07-08 Directory rename
    [pyvenv.cfg]
2023-07-09 Basic read/write support in the python module
    [pyvenv.cfg]
2023-07-10 Schematic cleanup
    [PicoROM.kicad_pcb, PicoROM.kicad_sch]
2023-07-10 Assert DTR signal since windows doesn't do it automatically
    [main.rs]
2023-07-11 Add jclpcb production files and KiCad BOM
    [BOM-PicoROM-3v3.csv, PicoROM.csv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]
2023-07-11 Disable serial uart Increase versions to 0.9.0 Mixed case firmware name
2023-07-14 Add LEDs and text
    [PicoROM.kicad_pcb, PicoROM.kicad_sch]
2023-07-15 Remove voltage selection resistors, use 5v Re-route around the buffer
    [PicoROM.kicad_pcb, PicoROM.kicad_sch]
2023-07-15 Version 1.2 as submitted for manufacture
    [BOM-PicoROM-5v-1_2.csv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]
2023-07-15 Update PCB image
2023-07-25 Use tud cdc directly, don't enable stdio usb
    Add activity LED
2023-07-26 Increase stack size to 640 bytes to prevent stack overflow in some exception handling situations. Flush write buffer when a new connection is started. Added support for flashing the activity LED Adde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
    [main.cpp, main.rs, pico_link.h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]
2023-07-26 Add usb activity to LED Bump everything up to version 1.0.0
2024-05-03 New pcb work
    [PicoROM-CuBottom.gbr, PicoROM-CuIn1.gbr, PicoROM-CuIn2.gbr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]
2024-05-06 Add io expander and hook up level shifters
    [PicoROM.kicad_pcb, PicoROM.kicad_sch]
2024-05-27 First pass routing complete
    [PicoROM.kicad_pcb, PicoROM.kicad_sch]
2024-05-27 Routing tweaks
    [PicoROM-CuBottom.gbr, PicoROM-CuIn1.gbr, PicoROM-CuIn2.gbr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]
2024-06-02 Improve GND and 3V3 paths around regulator Move LED resistors out of courtyard
    [PicoROM.kicad_pcb]
2024-06-07 Latest layout updates
    [PicoROM.kicad_pcb, PicoROM.kicad_sch]
2024-06-15 v1.5 hardware support IO Expander Reset pin functionality Change activity indicator to only trigger on the edge Remove old non-buffer paths
2024-06-15 Fix up compile errors when TCA is disabled Added two executables to support 1.2 and 1.5 boards
    [main.cpp, rom.cpp, system.h]
2024-06-15 Final v1.5 layout tweaks
    [BOM-PicoROM-3v3.csv, BOM-PicoROM-5v-1_2.csv, BOM-PicoROM.csv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]
2024-10-11 Reduced component sizes
    [PicoROM.kicad_pcb, PicoROM.kicad_sch]
2024-10-11 Switched to 6 layer, rerouted.
    [PicoROM.kicad_pcb, PicoROM.kicad_sch]
2024-10-12 Switch to 3/4.5 vias. Cleaned up routing
    [PicoROM.kicad_pcb, PicoROM.kicad_sch]
2024-10-15 Add pullups
    [PicoROM.kicad_pcb, PicoROM.kicad_sch]
2024-11-05 Pico SDK v2
2024-11-05 Disable data pin output enable when /CE and /OE are deasserted. Was causing high current usage.
2024-11-05 Reduce drive strength since we are going right into a buffer Write to data pins from SIO, don't use PIO. Reduces worst case access time from 92ns to 80ns at 200Mhz
2024-11-16 Clean up
    [PicoROM.kicad_pcb]
2024-11-20 Move flash code to separate file Load rom from flash using DMA
2024-11-24 Timer working but breaks I/O
2024-12-08 v1.7 Switch USB boot header to a 5pin header with SWD breakouts also. Added 3D models
    [DHVQFN24_L5.5-W3.5-H0.9-P0.50-BL-EP.step, PicoROM.kicad_pcb, PicoROM.kicad_sch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]
2024-12-10 Reduce max timer count in SDK to free up some RAM
2024-12-13 New way to organize PIO programs so switching things around is a little easier Use separate state machines for OE and pindirs with faster loop Disable syncronizers for OE inputs
2024-12-20 v2.0 firmware
    Add generic parameters and move most stuff to it
    Support for boot reset flags
    Support for multiple build configs
    Query and set parameters from picorom CLI and python
    2MBit build config and 1MBit build config with cycle counter
    [main.cpp, main.rs, pico_link.h]
2025-01-11 Add a cache for enumeration so not every device needs to be queried on every connect
2025-01-13 Stub out atexit because some versions of the sdk/newlib are not correctly stripping it
    [main.cpp]
2025-07-04 Added a slower 100ns access time version of the firmware To combat ringing/instability on the address lines of some boards, wait until the address has stabilized before fetching a byte.
    Added `name-swap` command to the picorom tool since it is something I
    find myself doing pretty frequently.
    [main.rs, rom.cpp]
2025-11-14 Hardware reorg
    [PicoROM.csv, PicoROM.kicad_pcb, PicoROM.kicad_sch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]
2025-11-14 Rename to PicoROM-32
    [PicoROM-32.kicad_pcb, PicoROM-32.kicad_sch]
2025-11-14 Split hardware project into PicoROM-32 and PicoROM-28
    Added new DIP-28 form factor PicoROM-28 design. Firmware not written
    yet.
    [PicoROM-28.kicad_pcb, PicoROM-28.kicad_sch, bom.csv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]
2025-12-01 PicoROM-28 v1.1
    Dual power supply
    [PicoROM-28.kicad_pcb, PicoROM-28.kicad_sch, bom.csv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]
2025-12-22 Tweaks for 1.2.
    Remove BUF_OE pull up
    [PicoROM-28.kicad_pcb, PicoROM-28.kicad_sch]
2025-12-27 Move pico-sdk to a submodule
2026-01-10 Created new 32-pin version from 28-pin version
    [PicoROM-32.kicad_pcb, PicoROM.kicad_pcb, PicoROM.kicad_sch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]
2026-01-11 Fix address line routing
    [PicoROM-32.kicad_pcb, PicoROM-32.kicad_sch, bom.csv]
2026-01-11 1.8 production files
    [PicoROM-28.kicad_pcb, PicoROM-28.kicad_sch, bom.csv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]
2026-01-21 Use correct 0201 capacitor part numbers Fix polarity of OR gate :(
    [PicoROM-28.kicad_pcb, PicoROM-28.kicad_sch, PicoROM-32.kicad_pcb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]
2026-01-21 Add new 32-pin target. Switch to using PWM for Info LED output
    [PicoROM-32.kicad_pcb]
2026-01-22 Changed direction of 74LVC8T245 so the control signals are on the 3.3V side (VCCA) Replaced the 74LVC2G125 with an 74AHCT2G126, LVC logic levels at 5v aren't TTL compatible. JLCPCB didn't have any 12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
    [PicoROM-28.kicad_pcb, PicoROM-28.kicad_sch, PicoROM-32.kicad_pcb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]
2026-01-30 Move reset and led handling out of main.cpp and rom.cpp into new peripherals.cpp
    [main.cpp, peripherals.cpp, rom.cpp]
2026-02-03 Fixes for 32P board
    28P and Legacy not tested yet
    [peripherals.cpp, rom.cpp]
2026-02-06 Include name in device serial string
2026-02-06 Use the device name from the USB descriptor serial string
2026-02-06 Half flash speed because not all boards can do full speed Fix 28P boards by initializing peripherals before starting the pios
    [main.cpp, peripherals.cpp, rom.cpp]
2026-02-07 Use reset interface instead of custom usb_boot command
    [main.cpp, main.rs, pico_link.h]
2026-02-07 Support firmware update on any rp2040 device
